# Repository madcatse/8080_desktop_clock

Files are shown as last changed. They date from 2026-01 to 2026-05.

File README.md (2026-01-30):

# i8080 homebrew digital clock/weather station (fork)

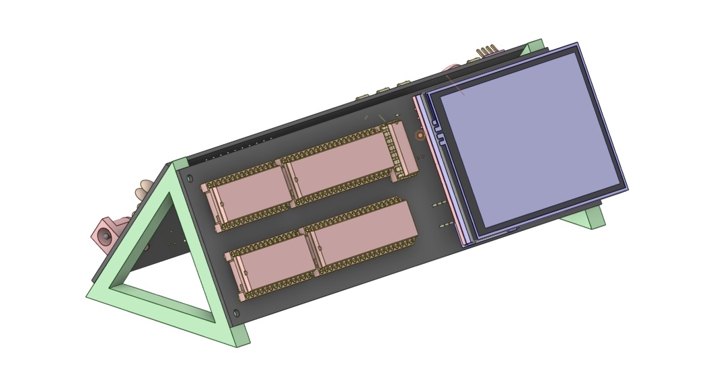
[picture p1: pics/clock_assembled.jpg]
Передняя плата

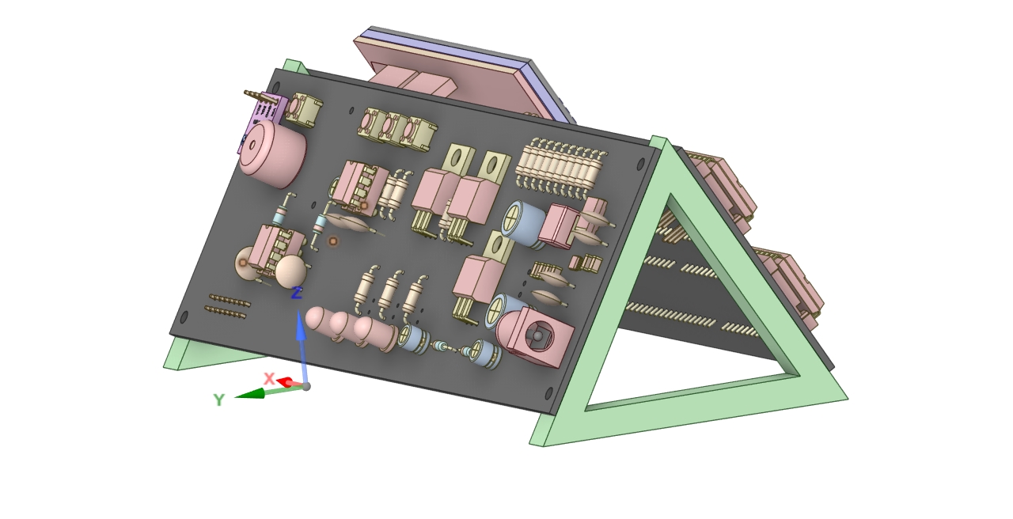
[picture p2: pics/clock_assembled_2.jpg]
Задняя плата

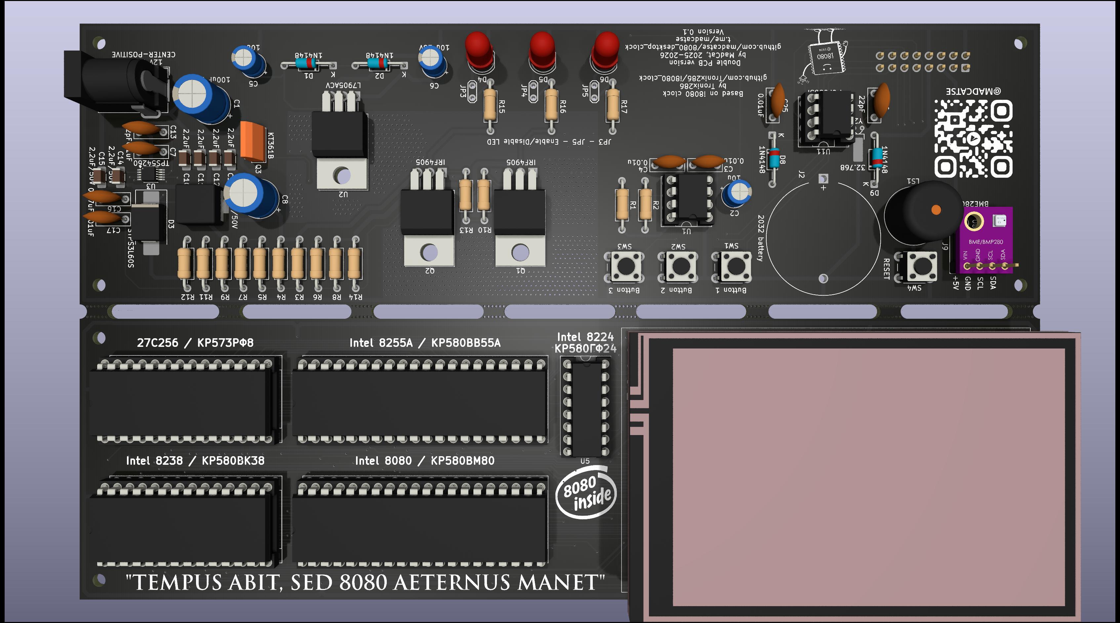
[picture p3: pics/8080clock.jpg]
Плата проекта в сборе


## Русский

Этот репозиторий — форк проекта **"i8080 homebrew digital clock/weather station"** автора **Tronix286**: 
<https://github.com/Tronix286/i8080_clock>.

Моя цель — сделать часы более презентабельными и свести к минимуму использование SMD‑компонентов (с таким процессором использовать их «не комильфо»). Я очень благодарен автору за схему и само устройство — без этой базы не получилось бы так быстро продвинуться.

Ключевое отличие от исходного проекта: в этом форке сделан упор на внешний вид и на максимально сквозной/выводной монтаж, поэтому плата и компоновка ориентированы на более «классическое» исполнение и удобство сборки, при сохранении общей архитектуры.

### Что внутри

**Аппаратная часть**
- Плата i8080‑совместимого компьютера с тактированием, шиной, ПЗУ/ОЗУ и часами реального времени.
- Внешние устройства: TFT‑дисплей, датчики по I2C и 1‑Wire, кнопки.

**Проект в KiCad**
- Полный проект схемы и платы находится в каталоге `hardware/`.

### ПО

Сборка прошивки описана в каталоге `software/` (используется z88dk и собственная цель `clock80`).

### 3D

Трехмерная модель собранных часов, а также модели треугольные ножки для 3d-печати.

---

## English

This repository is a fork of **"i8080 homebrew digital clock/weather station"** by **Tronix286**: 
<https://github.com/Tronix286/i8080_clock>.

My goal is to make the clock look more presentable and to minimize the number of SMD parts (with a CPU like this, using SMD feels out of place). I am very grateful to the author for the schematic and the original device — it provided the essential foundation for this work.

Key difference vs the original project: this fork focuses on the physical appearance and on keeping the design as through‑hole as possible. The PCB layout and mechanical decisions are tailored to a more classic, build‑friendly presentation while preserving the overall architecture.

### What’s inside

**Hardware**
- i8080‑compatible system board with clocking, bus, ROM/RAM, and real‑time clock.
- External devices: TFT display, I2C and 1‑Wire sensors, and buttons.

**KiCad project**
- Full schematic and PCB project live under `hardware/`.

### Software

Firmware build instructions and sources are in `software/` (z88dk with a custom `clock80` target).

### 3D

3D model of assembled clock, and models of triangle stands for 3d printing.

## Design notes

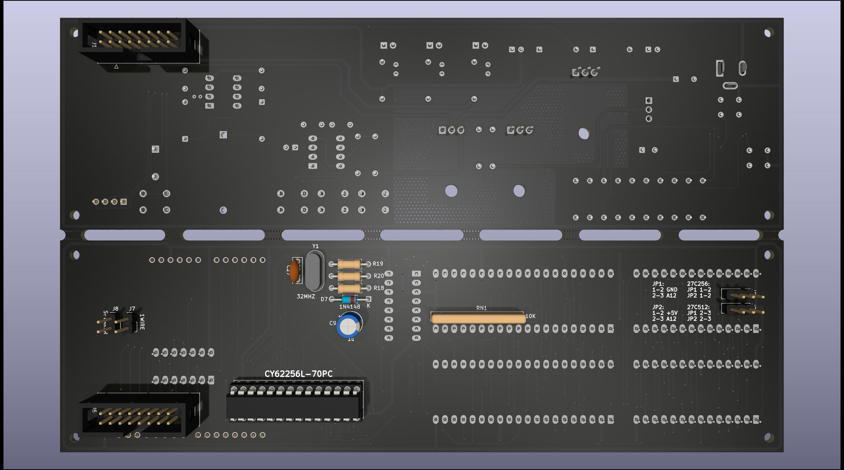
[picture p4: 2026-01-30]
pics/8080clock_backside.jpg

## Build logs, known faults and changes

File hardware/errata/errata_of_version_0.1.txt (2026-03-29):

сдвинуть резисторную сборку
диаметры вентиляционных отверстий
сделать упоминание про конденсаторы, может сделать новые отверстия
дорожка питания к часовой микросхеме
переразвернуть платы чтобы они соединялись снизу, чтобы не шлифовать верх плат
Транзистор заменить на Кт315 или BC337 и поправить цоколевку

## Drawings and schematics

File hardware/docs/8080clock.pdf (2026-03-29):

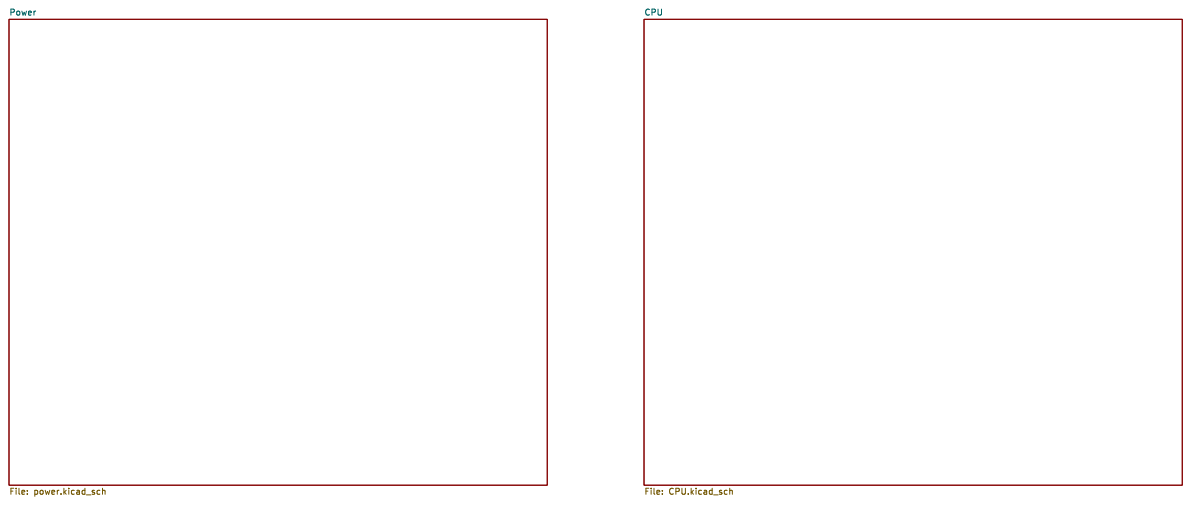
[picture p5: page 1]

Id: 1/3 Title: File: 8080clock.kicad_sch Sheet: /

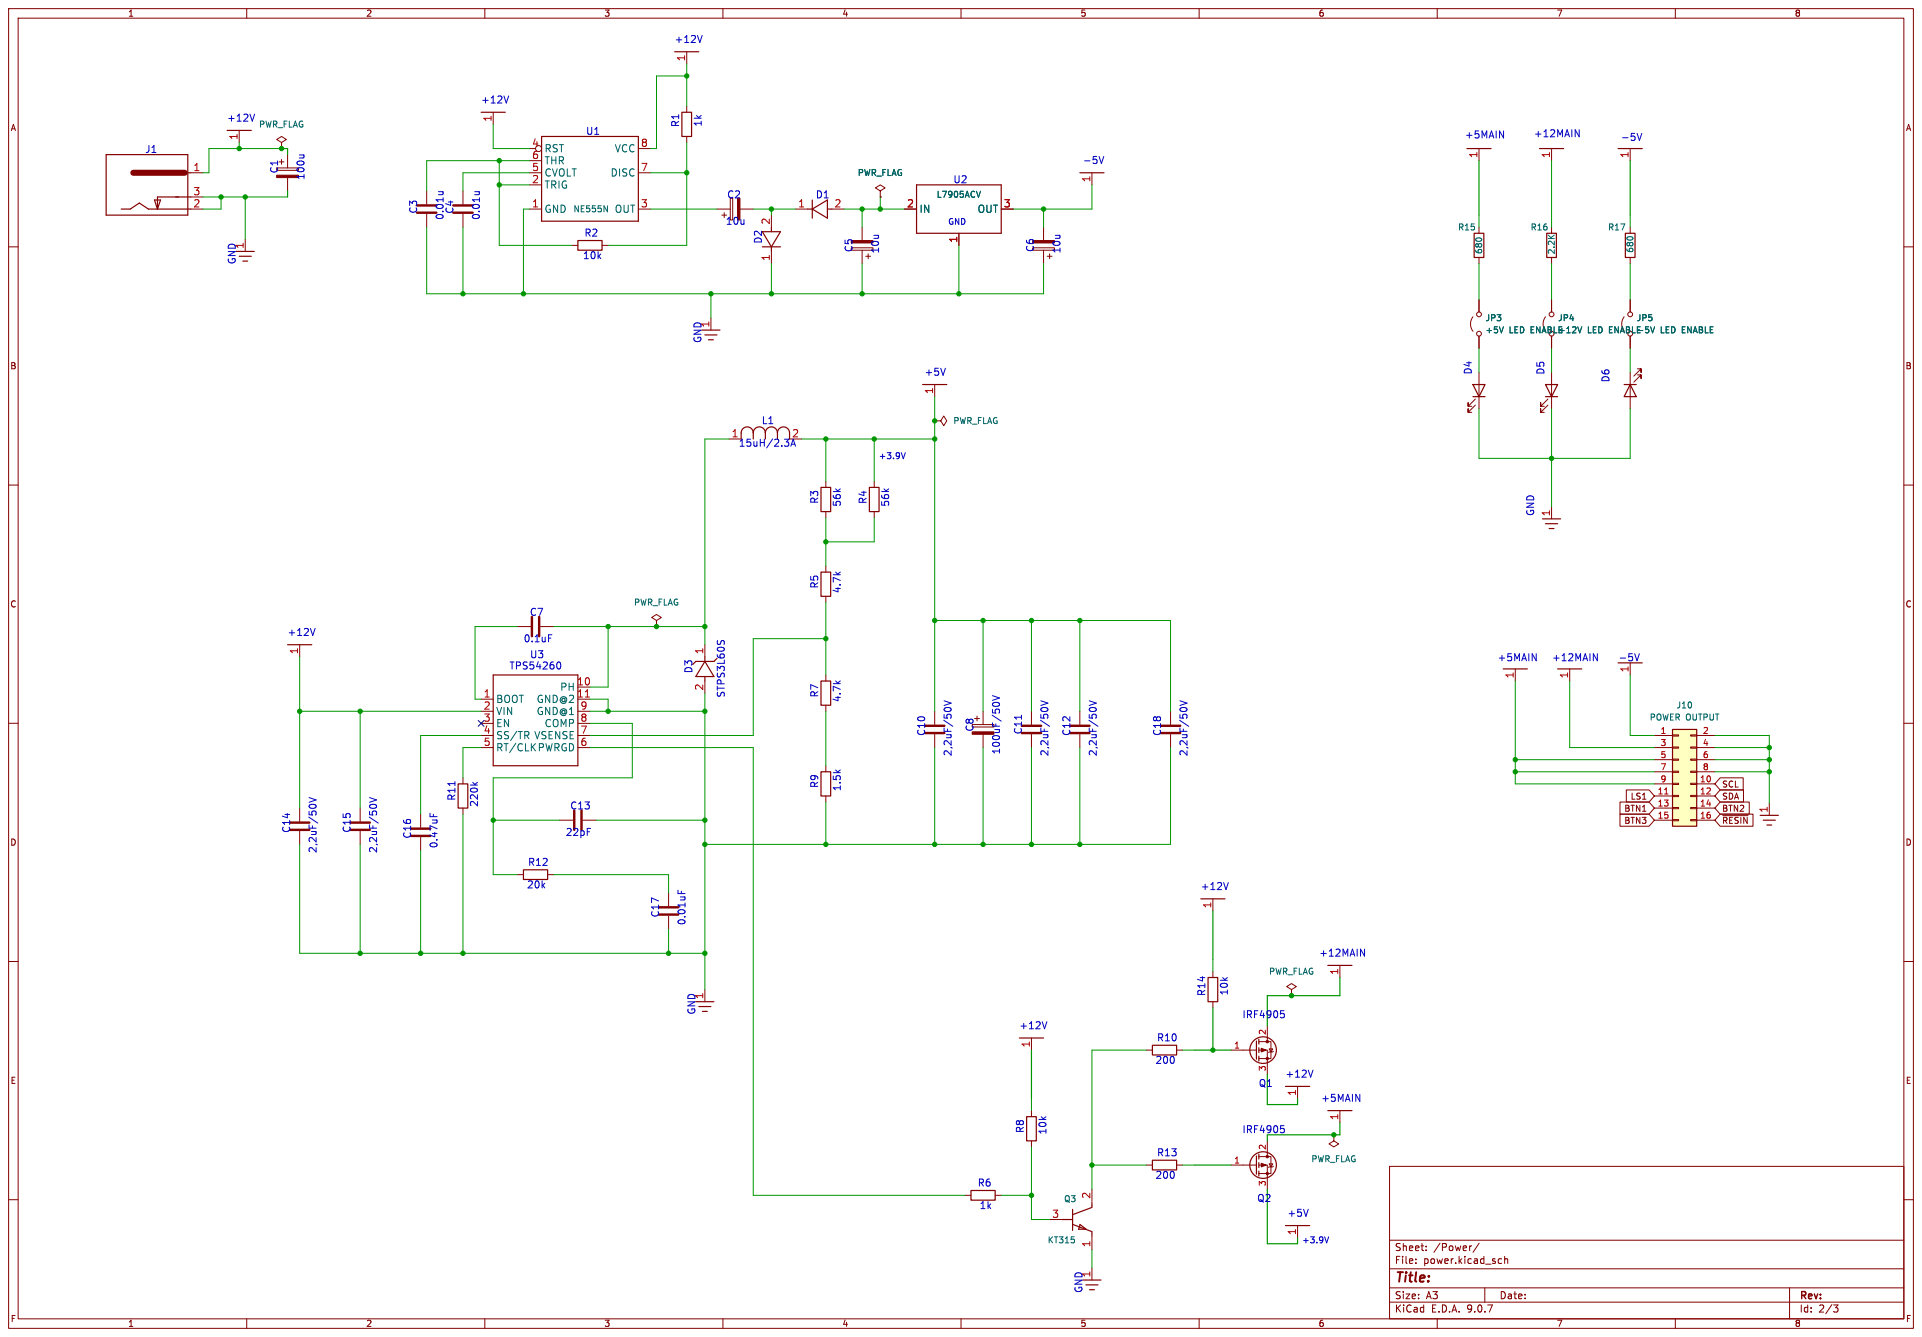
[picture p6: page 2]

1 RST 4 THR 6 CVOLT 5 TRIG 2 GND 1 VCC 8 DISC 7 OUT 3 NE555N

1 BOOT 1 VIN 2 EN 3 SS/TR 4 RT/CLK 5 PH 10 GND@2 11 GND@1 9 COMP 8 VSENSE 7 PWRGD 6

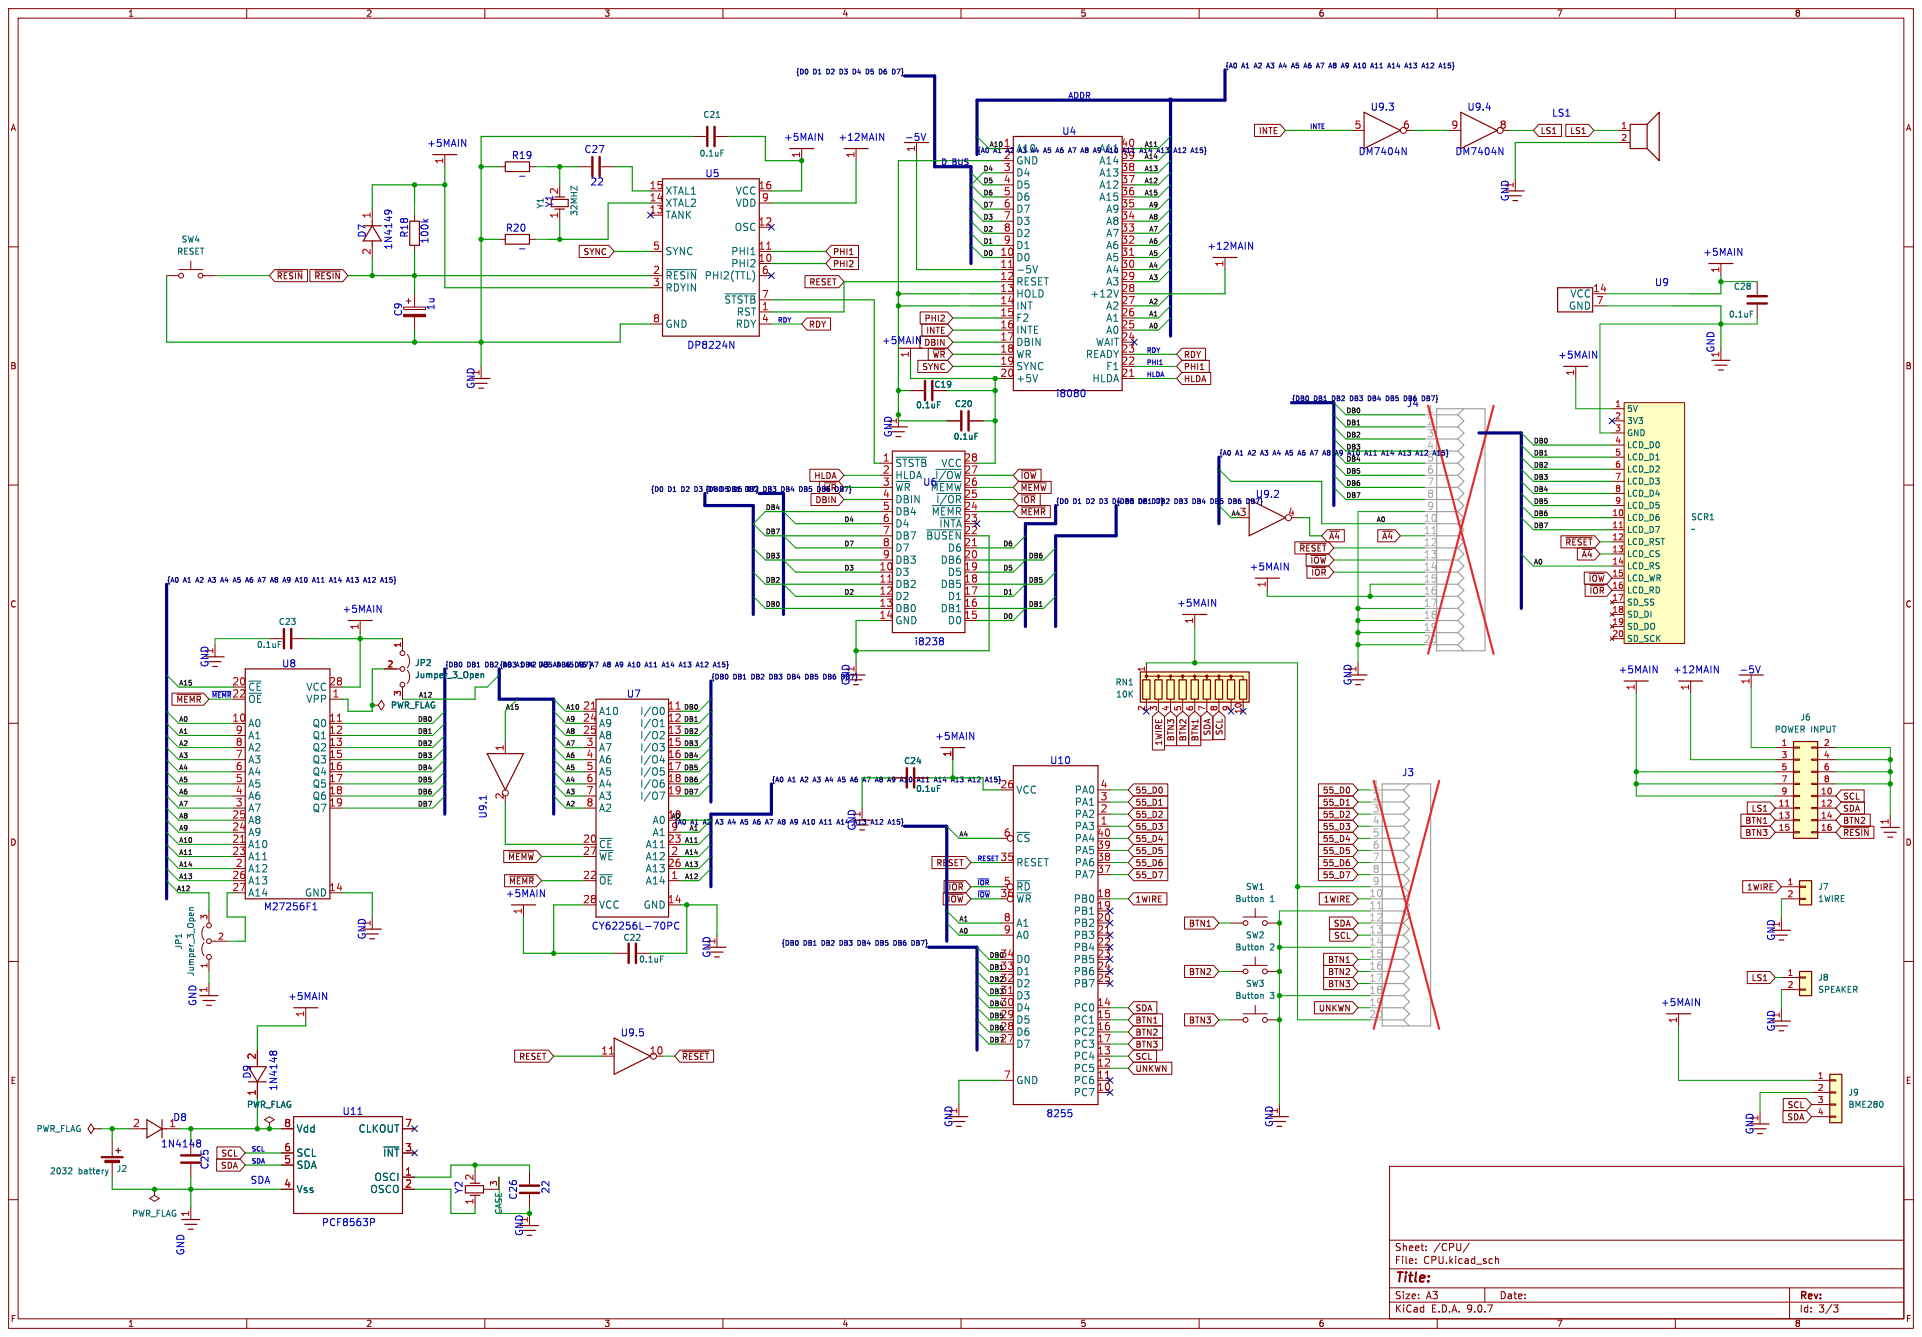
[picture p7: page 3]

1 A10 21 A9 24 A8 25 A7 3 A6 4 A5 5 A4 6 A3 7 A2 8 ~{CE} 20 ~{WE} 27 ~{OE} 22 VCC 28

1 XTAL1 15 XTAL2 14 TANK 13 SYNC 5 ~{RESIN} 2 RDYIN 3 GND 8 VCC16 VDD 9 OSC 12 PHI1 11 PHI2 10 PHI2(TTL) 6 ~{STSTB}7 RST 1 RDY 4 C20

1 ~{STSTB} 1 HLDA 2 ~{WR} 3 DBIN 4 DB4 5 D4 6 DB7 7 D7 8 DB3 9 D3 10 DB2 11 D2 12 DB0 13 GND 14 VCC28 ~{I/OW}27 ~{MEMW} 26 ~{I/OR}25 ~{MEMR} 24 ~{INTA} 23 ~{BUSEN} 22 D6 21 DB6 20 D5 19 DB5 18 D1 17 DB1 16 D0 15

1 VCC 26 ~{CS} 6 RESET 35 ~{RD} 5 ~{WR} 36 A1 8 A0 9 D0 34 D1 33 D2 32 D3 31 D4 30 D5 29 D6 28 D7 27 GND 7 PA0 4 PA1 3 PA2 2 PA3 1 PA4 40 PA5 39 PA6 38 PA7 37 PB0 18 PB1 19 PB2 20 PB3 21 PB4 22 PB5 23 PB6 24 PB7 25 PC0 14 PC1 15 PC2 16 PC3 17 PC4 13 PC5 12 PC6 11 PC7 10

Id: 3/3 Title: File: CPU.kicad_sch Sheet: /CPU/

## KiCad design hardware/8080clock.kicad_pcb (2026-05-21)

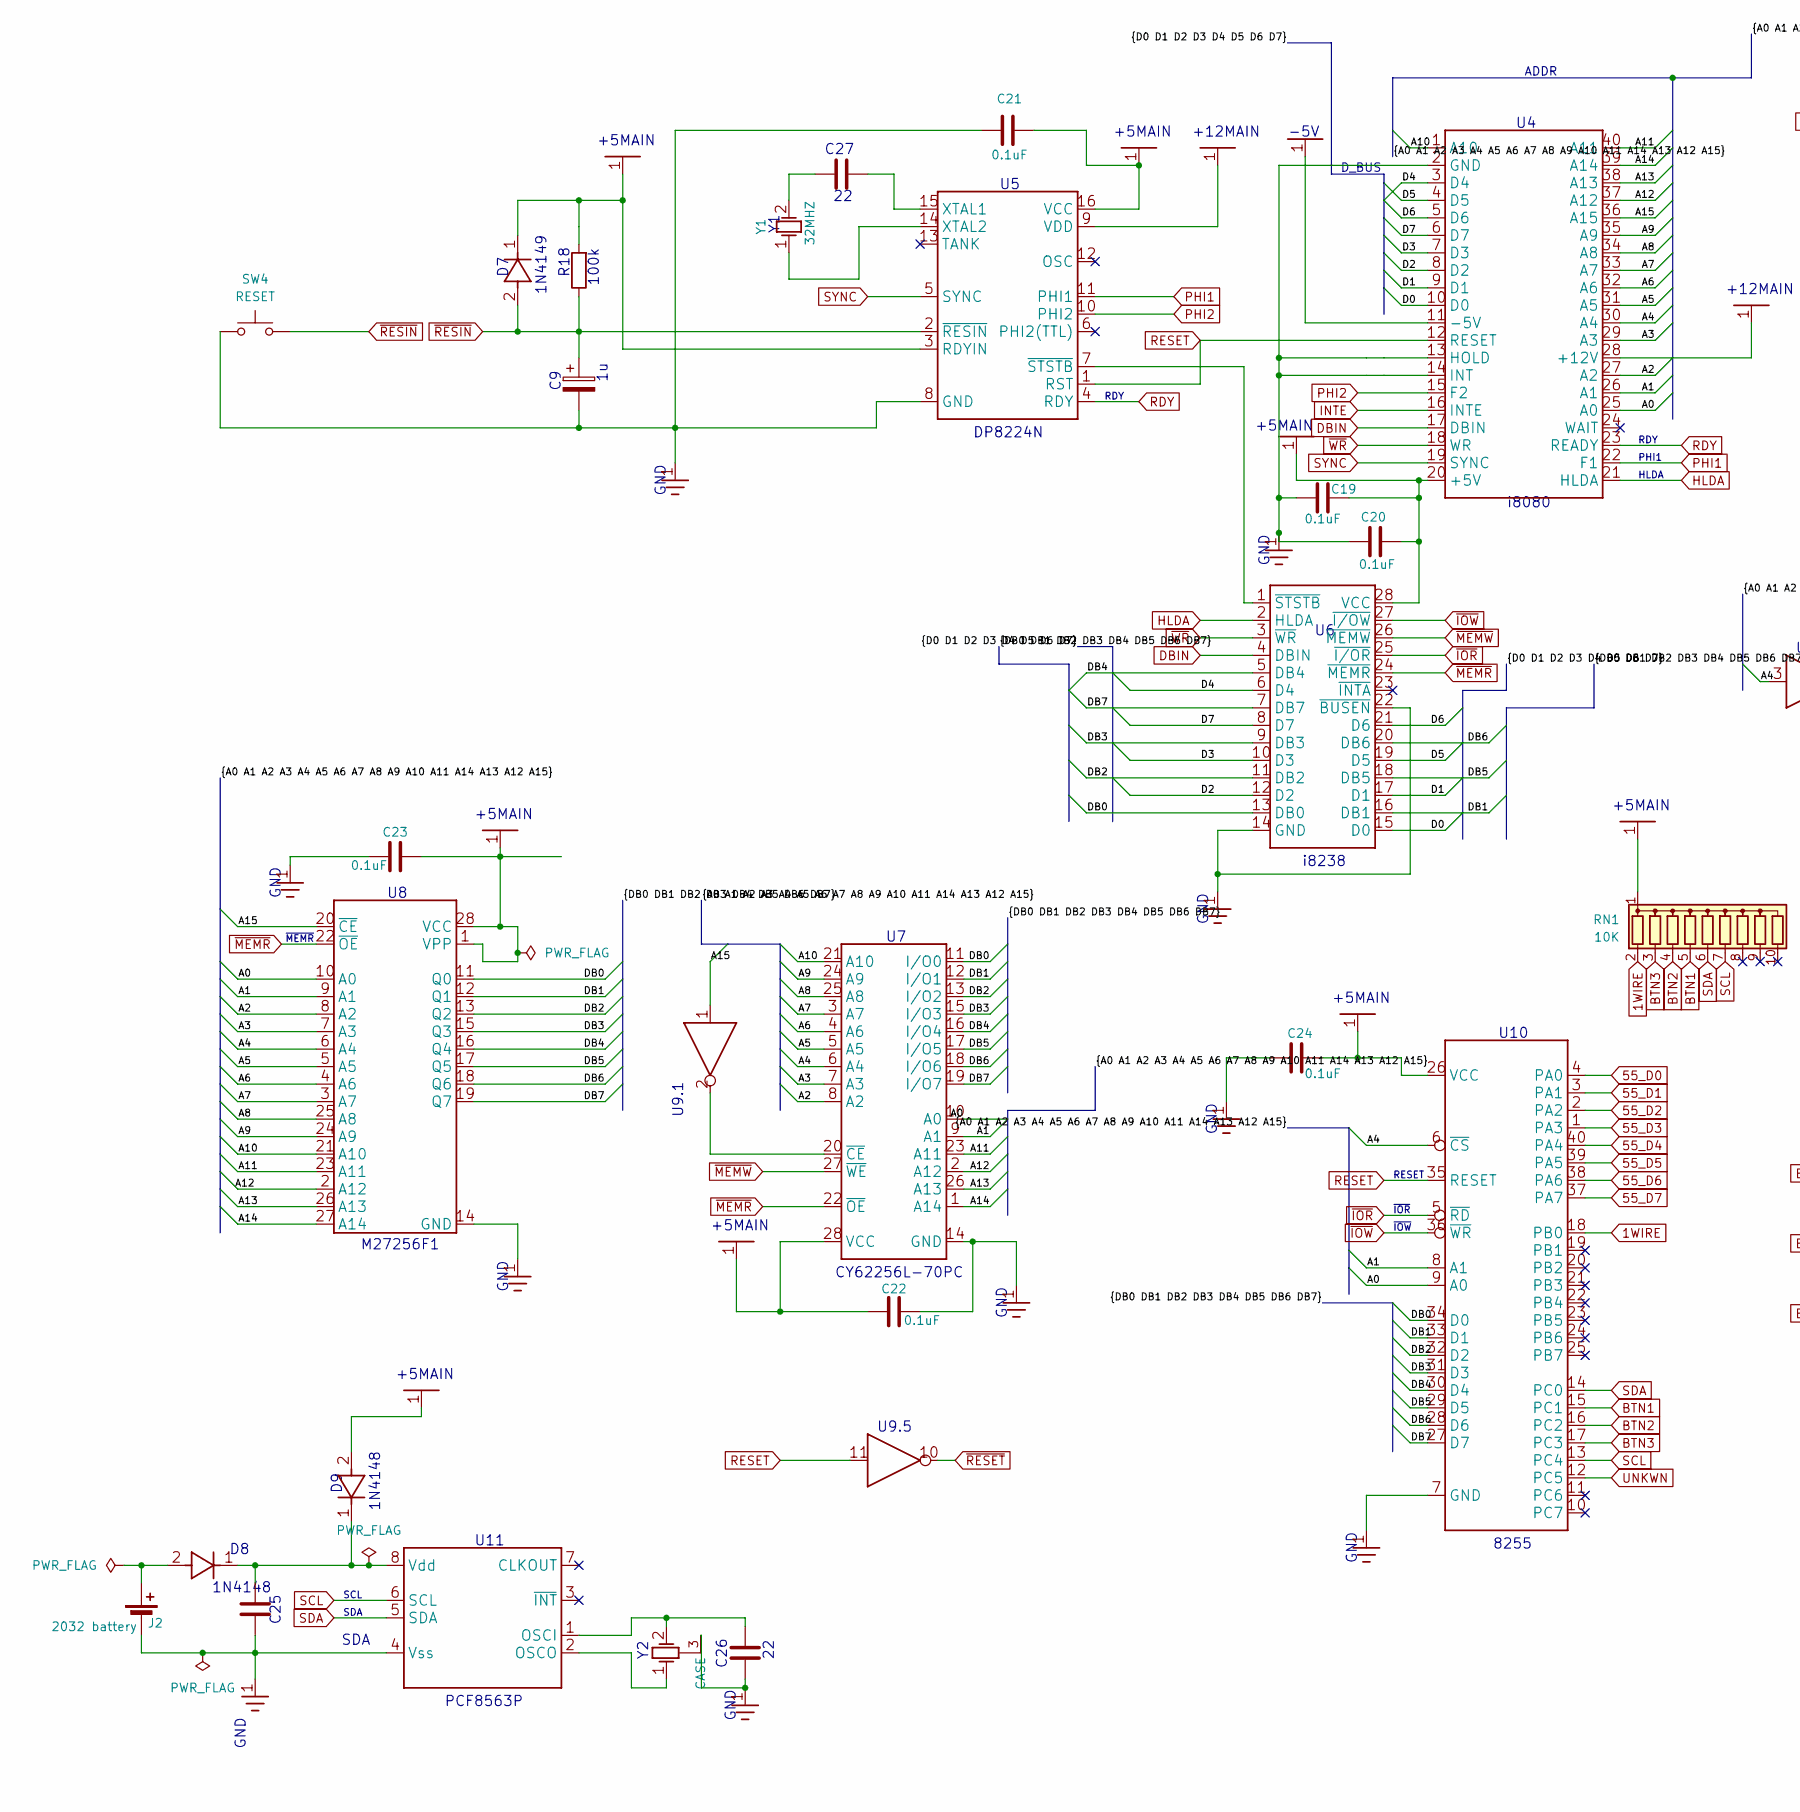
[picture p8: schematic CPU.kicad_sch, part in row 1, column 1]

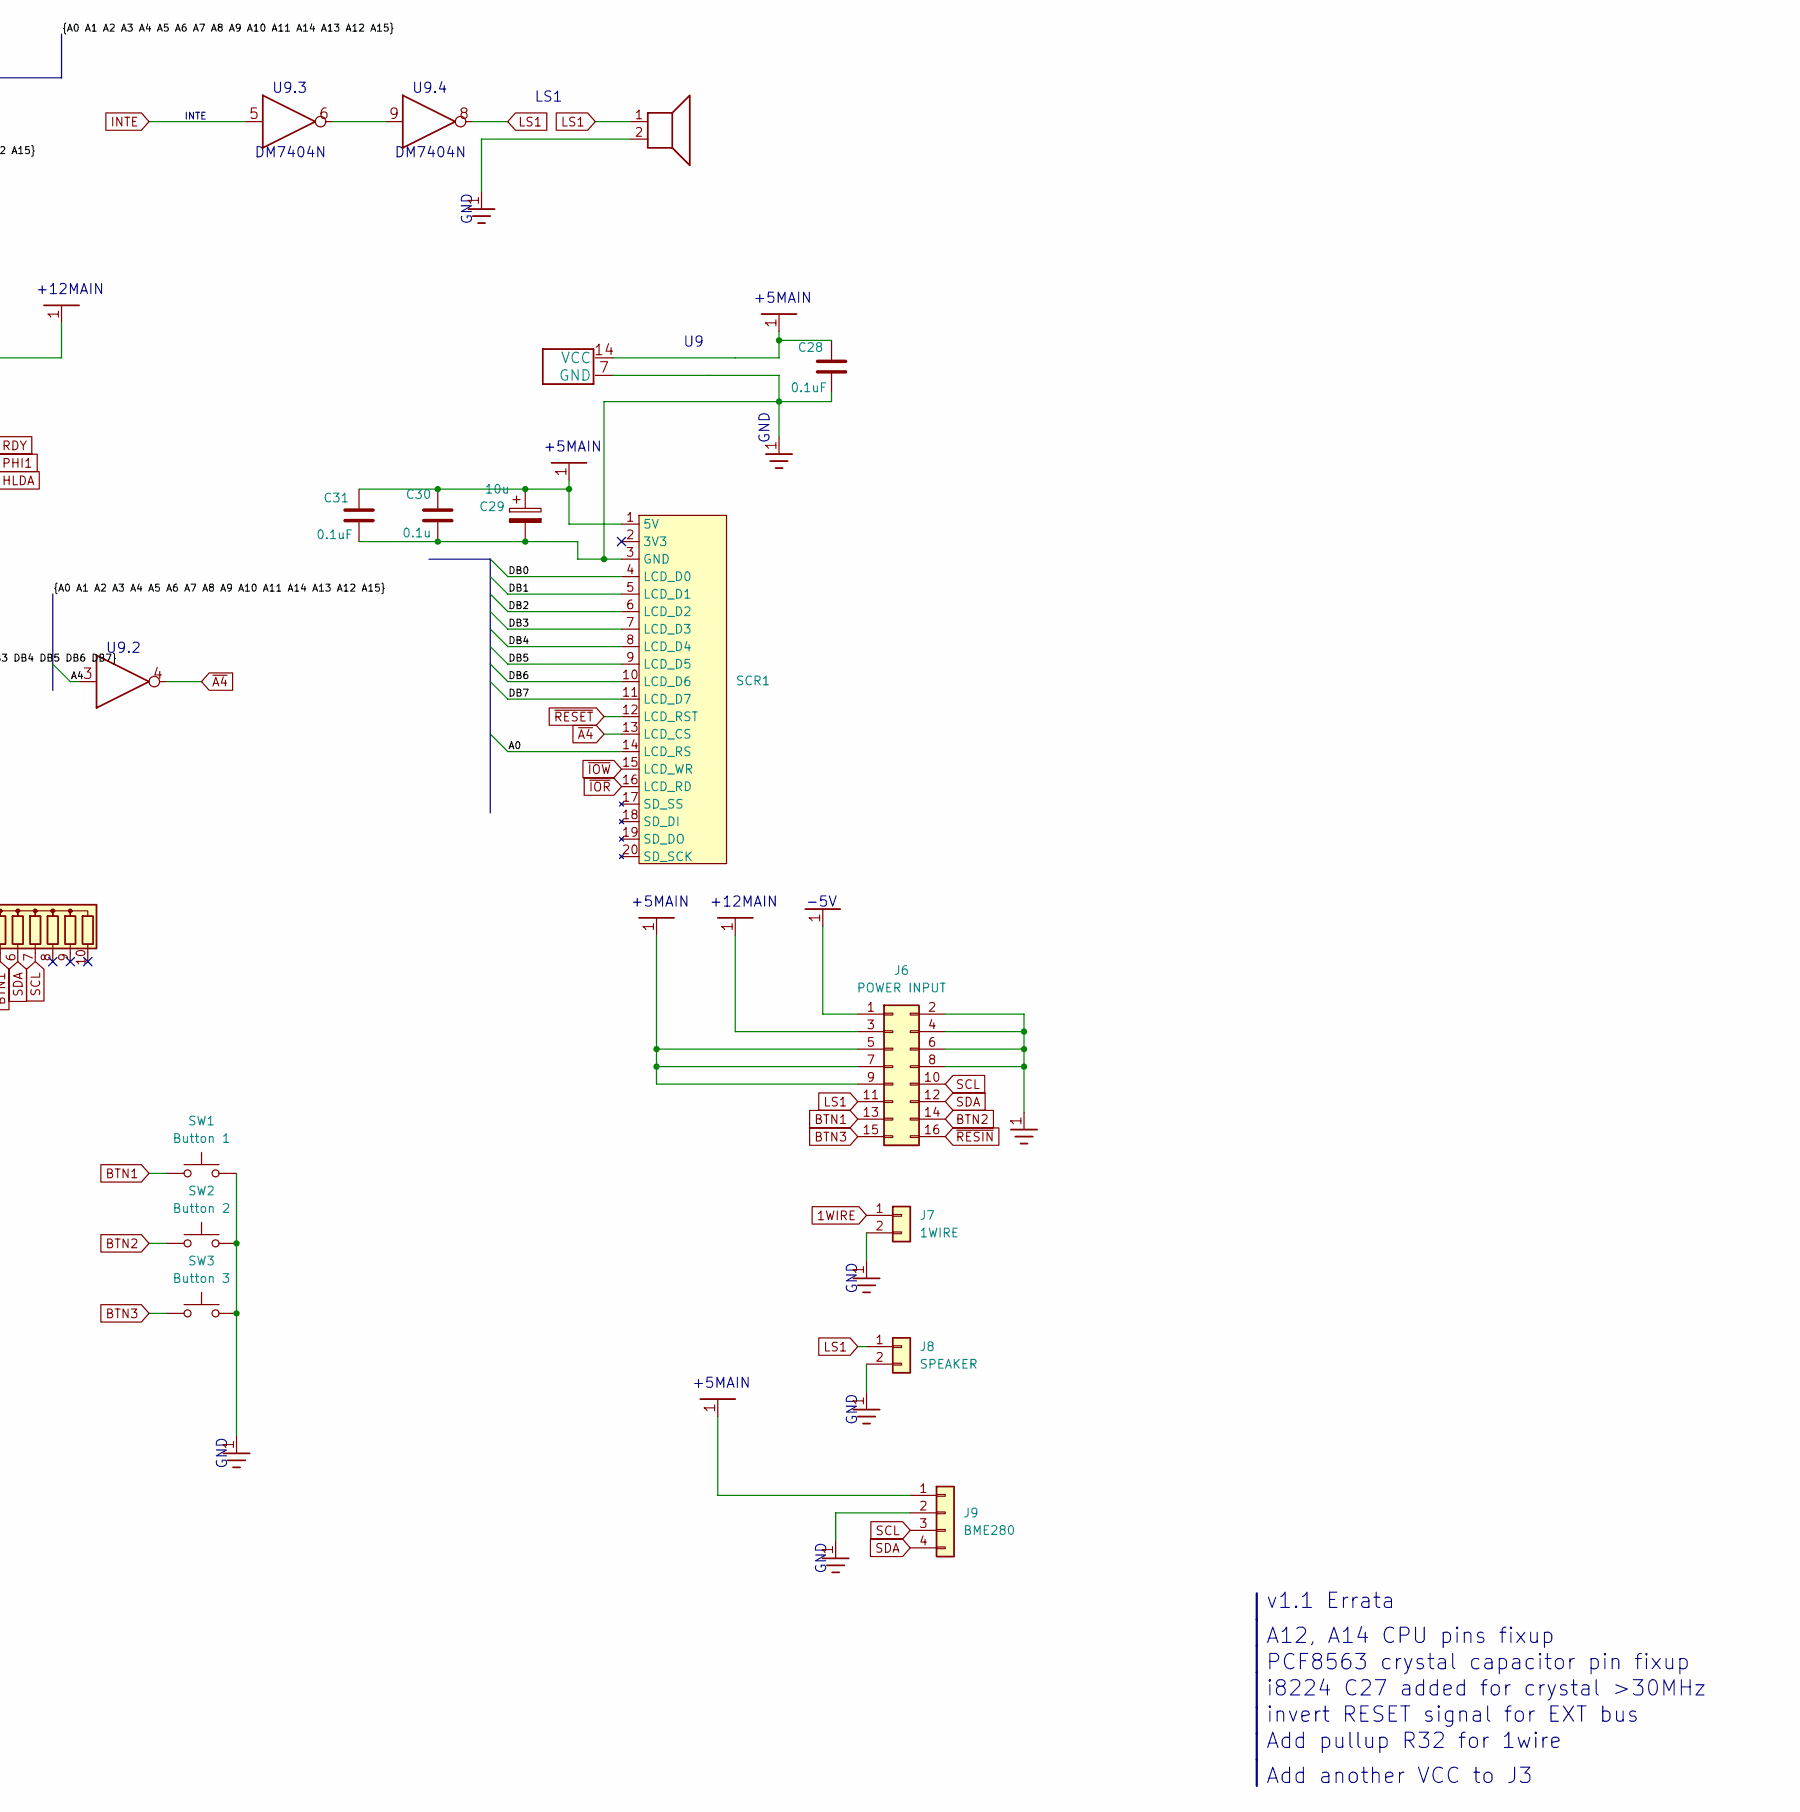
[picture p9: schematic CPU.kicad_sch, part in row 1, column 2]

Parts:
C9: 1u; CP_Radial_D6.3mm_P2.50mm
C19, C20, C21, C22, C23, C24, C28, C31: 0.1uF; C_Disc_D7.0mm_W2.5mm_P5.00mm
C25: 0.01uF; C_Disc_D7.0mm_W2.5mm_P5.00mm
C26, C27: 22pF; C_Disc_D7.0mm_W2.5mm_P5.00mm
C29: 10u; CP_Radial_D5.0mm_P2.50mm
C30: 0.1u; C_Disc_D7.0mm_W2.5mm_P5.00mm
D7, D8, D9: 1N4148; D_DO-35_SOD27_P10.16mm_Horizontal
J2: 2032 battery; BatteryHolder_MYOUNG_BS-07-A1BJ001_CR2032
J6: POWER INPUT; IDC-Header_2x08_P2.54mm_Vertical
J7: 1WIRE; PinHeader_1x02_P2.54mm_Vertical
J8: SPEAKER; PinHeader_1x02_P2.54mm_Vertical
J9: BME280; BME280_sensor
LS1: AI-1223-TWT-5V-R; Buzzer_12x9.5RM7.6
R18: 100k; R_Axial_DIN0207_L6.3mm_D2.5mm_P10.16mm_Horizontal
RN1: 10K; R_Array_SIP10
SCR1: SCREEN
SW1: Button 1; SW_PUSH_6mm
SW2: Button 2; SW_PUSH_6mm
SW3: Button 3; SW_PUSH_6mm
SW4: RESET; SW_PUSH_6mm
U5: Intel 8224 / КР580ГФ24; DIP-16_W7.62mm_Socket_LongPads
U6: Intel 8238 / КР580ВК38; DIP-28_W15.24mm_Socket_LongPads
U7: CY62256L-70PC; DIP-28_W7.62mm_Socket_LongPads
U8: 27C256 / КР573РФ8; DIP-28_W15.24mm_Socket_LongPads
U9: 74LS04 / К555ЛН1; DIP-14_W7.62mm_Socket_LongPads
U10: Intel 8255A / КР580ВВ55А; DIP-40_W15.24mm_Socket_LongPads
U11: PCF8563P; DIP-8_W7.62mm_Socket_LongPads
U12: Intel 8080 / КР580ВМ80; DIP-40_W15.24mm_Socket_LongPads
Y1: 32MHZ; Crystal_HC49-4H_Vertical
Y2: 32.768; Crystal_DS15_D1.5mm_L5.0mm_Horizontal_1EP_style1

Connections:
1WIRE: J7.1, RN1.2 (R1), U10.18 (PB0)
55_D0: U10.4 (PA0)
55_D1: U10.3 (PA1)
55_D2: U10.2 (PA2)
55_D3: U10.1 (PA3)
55_D4: U10.40 (PA4)
55_D5: U10.39 (PA5)
55_D6: U10.38 (PA6)
55_D7: U10.37 (PA7)
+5MAIN: C19.2, C20.2, C21.1, C22.1, C23.2, C24.2, C28.2, C29.1, C30.2, C31.2, D7.1 (K), D9.2 (A), J6.5, J6.7, J6.9, J9.1, R18.2, RN1.1 (common), SCR1.1 (5V), U5.3 (RDYIN), U5.16 (VCC), U6.28 (VCC), U7.28 (VCC), U8.1 (VPP), U8.28 (VCC), U9.14 (VCC), U10.26 (VCC), U12.20 (+5V); also elsewhere on the board
+12MAIN: J6.3, U5.9 (VDD), U12.28 (+12V); also elsewhere on the board
-5V: J6.1, U12.11 (-5V); also elsewhere on the board
/CPU/A0: SCR1.14 (LCD_RS), U7.10 (A0), U8.10 (A0), U10.9 (A0), U12.25 (A0)
/CPU/A1: U7.9 (A1), U8.9 (A1), U10.8 (A1), U12.26 (A1)
/CPU/A2: U7.8 (A2), U8.8 (A2), U12.27 (A2)
/CPU/A3: U7.7 (A3), U8.7 (A3), U12.29 (A3)
/CPU/A4: U7.6 (A4), U8.6 (A4), U9.3 (A), U10.6 (~CS), U12.30 (A4)
/CPU/A5: U7.5 (A5), U8.5 (A5), U12.31 (A5)
/CPU/A6: U7.4 (A6), U8.4 (A6), U12.32 (A6)
/CPU/A7: U7.3 (A7), U8.3 (A7), U12.33 (A7)
/CPU/A8: U7.25 (A8), U8.25 (A8), U12.34 (A8)
/CPU/A9: U7.24 (A9), U8.24 (A9), U12.35 (A9)
/CPU/A10: U7.21 (A10), U8.21 (A10), U12.1 (A10)
/CPU/A11: U7.23 (A11), U8.23 (A11), U12.40 (A11)
/CPU/A12: U7.2 (A12), U8.2 (A12), U12.37 (A12)
/CPU/A13: U7.26 (A13), U8.26 (A13), U12.38 (A13)
/CPU/A14: U7.1 (A14), U8.27 (A14), U12.39 (A14)
/CPU/A15: U8.20 (~CE), U9.1 (A), U12.36 (A15)
/CPU/D0: U6.15 (D0), U12.10 (D0)
/CPU/D1: U6.17 (D1), U12.9 (D1)
/CPU/D2: U6.12 (D2), U12.8 (D2)
/CPU/D3: U6.10 (D3), U12.7 (D3)
/CPU/D4: U6.6 (D4), U12.3 (D4)
/CPU/D5: U6.19 (D5), U12.4 (D5)
/CPU/D6: U6.21 (D6), U12.5 (D6)
/CPU/D7: U6.8 (D7), U12.6 (D7)
/CPU/DB0: SCR1.4 (LCD_D0), U6.13 (DB0), U7.11 (I/O0), U8.11 (Q0), U10.34 (D0)
/CPU/DB1: SCR1.5 (LCD_D1), U6.16 (DB1), U7.12 (I/O1), U8.12 (Q1), U10.33 (D1)
/CPU/DB2: SCR1.6 (LCD_D2), U6.11 (DB2), U7.13 (I/O2), U8.13 (Q2), U10.32 (D2)
/CPU/DB3: SCR1.7 (LCD_D3), U6.9 (DB3), U7.15 (I/O3), U8.15 (Q3), U10.31 (D3)
/CPU/DB4: SCR1.8 (LCD_D4), U6.5 (DB4), U7.16 (I/O4), U8.16 (Q4), U10.30 (D4)
/CPU/DB5: SCR1.9 (LCD_D5), U6.18 (DB5), U7.17 (I/O5), U8.17 (Q5), U10.29 (D5)
/CPU/DB6: SCR1.10 (LCD_D6), U6.20 (DB6), U7.18 (I/O6), U8.18 (Q6), U10.28 (D6)
/CPU/DB7: SCR1.11 (LCD_D7), U6.7 (DB7), U7.19 (I/O7), U8.19 (Q7), U10.27 (D7)
BTN1: J6.13, RN1.5 (R4), SW1.2, U10.15 (PC1); also elsewhere on the board
BTN2: J6.14, RN1.4 (R3), SW2.2, U10.16 (PC2); also elsewhere on the board
BTN3: J6.15, RN1.3 (R2), SW3.2, U10.17 (PC3); also elsewhere on the board
DBIN: U6.4 (DBIN), U12.17 (DBIN)
GND: C9.2, C19.1, C20.1, C21.2, C22.2, C23.1, C24.1, C25.1, C26.2, C28.1, C29.2, C30.1, C31.1, J2.2 (-), J6.2, J6.4, J6.6, J6.8, J7.2, J8.2, J9.2, LS1.2, SCR1.3 (GND), SW1.1, SW2.1, SW3.1, SW4.2, U5.8 (GND), U6.14 (GND), U6.22 (~BUSEN), U7.14 (GND), U8.14 (GND), U9.7 (GND), U10.7 (GND), U11.4 (Vss), U12.2 (GND), U12.13 (HOLD), U12.14 (INT), Y2.3 (CASE); also elsewhere on the board
HLDA: U6.2 (HLDA), U12.21 (HLDA)
INTE: U9.5 (A), U12.16 (INTE)
LS1: J6.11, J8.1, LS1.1, U9.8 (Y); also elsewhere on the board
unnamed: D8.2 (A), J2.1 (+)
unnamed: C25.2, D8.1 (K), D9.1 (K), U11.8 (Vdd)
unnamed: C27.2, U5.15 (XTAL1)
unnamed: U5.14 (XTAL2), Y1.1 (OSC1)
unnamed: U5.7 (~STSTB), U6.1 (~STSTB)
unnamed: U7.20 (~CE), U9.2 (Y)
unnamed: U9.6 (Y), U9.9 (A)
unnamed: C26.1, U11.1 (OSCI), Y2.2 (OSC2)
unnamed: U11.2 (OSCO), Y2.1 (OSC1)
unnamed: C27.1, Y1.2 (OSC2)
PHI1: U5.11 (PHI1), U12.22 (F1)
PHI2: U5.10 (PHI2), U12.15 (F2)
RDY: U5.4 (RDY), U12.23 (READY)
RESET: U5.1 (RST), U9.11 (A), U10.35 (RESET), U12.12 (RESET)
SCL: J6.10, J9.3, RN1.7 (R6), U10.13 (PC4), U11.6 (SCL); also elsewhere on the board
SDA: J6.12, J9.4, RN1.6 (R5), U10.14 (PC0), U11.5 (SDA); also elsewhere on the board
SYNC: U5.5 (SYNC), U12.19 (SYNC)
UNKWN: U10.12 (PC5)
~A4: SCR1.13 (LCD_CS), U9.4 (Y)
~IOR: SCR1.16 (LCD_RD), U6.25 (~I/OR), U10.5 (~RD)
~IOW: SCR1.15 (LCD_WR), U6.27 (~I/OW), U10.36 (~WR)
~MEMR: U6.24 (~MEMR), U7.22 (~OE), U8.22 (~OE)
~MEMW: U6.26 (~MEMW), U7.27 (~WE)
~RESET: SCR1.12 (LCD_RST), U9.10 (Y)
~RESIN: C9.1, D7.2 (A), J6.16, R18.1, SW4.1, U5.2 (~RESIN); also elsewhere on the board
~WR: U6.3 (~WR), U12.18 (WR)

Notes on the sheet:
GND
-5V
U9.2
LS1
U9.3
1N4148
R18
+5MAIN
PCF8563 crystal capacitor pin fixup
SDA
A12, A14 CPU pins fixup
D_BUS
U9.1
~{IOR}
+12MAIN
Add another VCC to J3
RDY
~{IOW}
U9.4
100k
DM7404N
C27
U10
C25
C26
CY62256L-70PC
PHI1
v1.1 Errata
~{MEMR}
U9.5
invert RESET signal for EXT bus
PCF8563P
INTE
RESET
i8080
SCL
HLDA
Add pullup R32 for 1wire
i8224 C27 added for crystal >30MHz
M27256F1

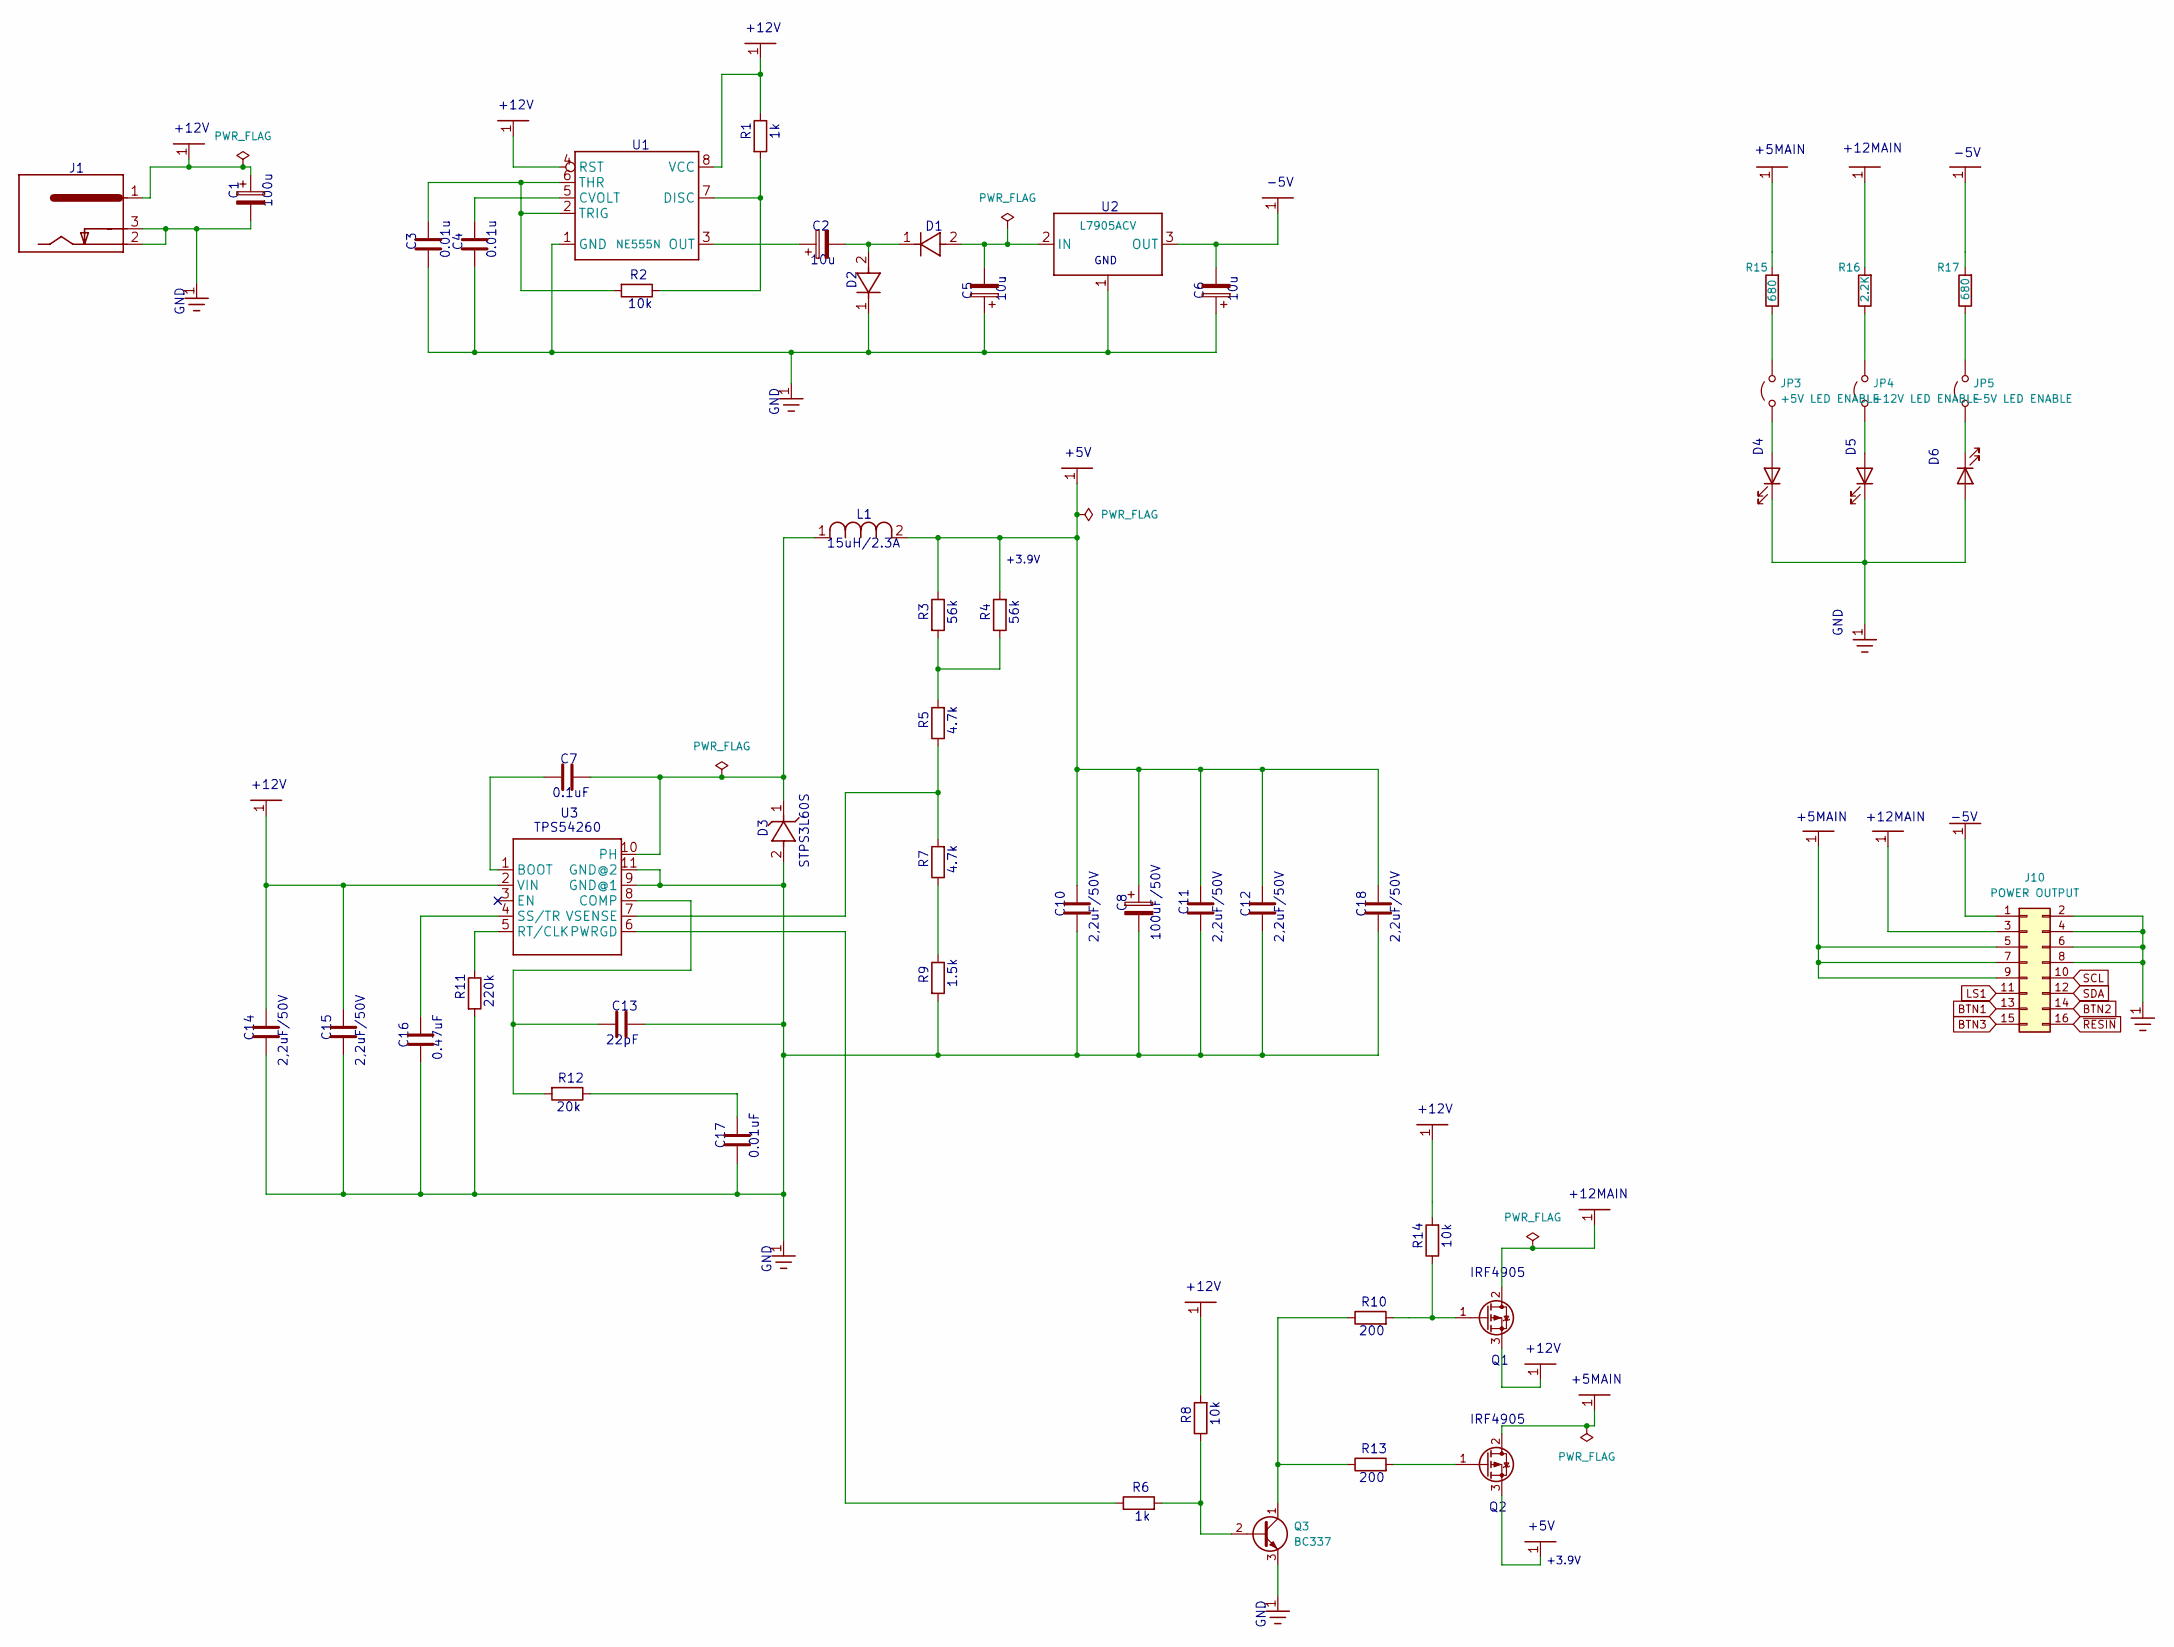
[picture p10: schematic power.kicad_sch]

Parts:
C1: 100uF 25V; CP_Radial_D8.0mm_P5.00mm
C2, C5: 10u; CP_Radial_D5.0mm_P2.50mm
C3, C4: 0.01u; C_Disc_D7.0mm_W2.5mm_P5.00mm
C6: 10u 16V; CP_Radial_D5.0mm_P2.50mm
C7: 0.1uF; C_Disc_D7.0mm_W2.5mm_P5.00mm
C8: 100uF/50V; CP_Radial_D8.0mm_P3.50mm
C10, C11, C12, C18: 2,2uF; C_1206_3216Metric_Pad1.33x1.80mm_HandSolder
C13: 22pF; C_Disc_D7.0mm_W2.5mm_P5.00mm
C14, C15: 2,2uF/50V; C_1206_3216Metric_Pad1.33x1.80mm_HandSolder
C16: 0.47uF; C_Disc_D7.0mm_W2.5mm_P5.00mm
C17: 0.01uF; C_Disc_D7.0mm_W2.5mm_P5.00mm
D1, D2: 1N4148; D_DO-35_SOD27_P10.16mm_Horizontal
D3: STPS3L60S; D_SMC_Handsoldering
D4: +5V; LED_D5.0mm
D5: +12V; LED_D5.0mm
D6: -5V; LED_D5.0mm
J1: 4840-2201; BarrelJack_GCT_DCJ200-10-A_Horizontal
J10: POWER OUTPUT; IDC-Header_2x08_P2.54mm_Vertical
JP3: +5V LED ENABLE; TestPoint_2Pads_Pitch2.54mm_Drill0.8mm
JP4: +12V LED ENABLE; TestPoint_2Pads_Pitch2.54mm_Drill0.8mm
JP5: -5V LED ENABLE; TestPoint_2Pads_Pitch2.54mm_Drill0.8mm
L1: 15uH/2.3A; CDRH8D43NP-100NC
Q1, Q2: IRF4905; TO-220-3_Horizontal_TabDown
Q3: BC337; TO-92L_Inline
R1, R6: 1k; R_Axial_DIN0207_L6.3mm_D2.5mm_P10.16mm_Horizontal
R2, R8, R14: 10k; R_Axial_DIN0207_L6.3mm_D2.5mm_P10.16mm_Horizontal
R3, R4: 56k; R_Axial_DIN0207_L6.3mm_D2.5mm_P10.16mm_Horizontal
R5, R7: 4.7k; R_Axial_DIN0207_L6.3mm_D2.5mm_P10.16mm_Horizontal
R9: 1.5k; R_Axial_DIN0207_L6.3mm_D2.5mm_P10.16mm_Horizontal
R10, R13: 200; R_Axial_DIN0207_L6.3mm_D2.5mm_P10.16mm_Horizontal
R11: 220k; R_Axial_DIN0207_L6.3mm_D2.5mm_P10.16mm_Horizontal
R12: 20k; R_Axial_DIN0207_L6.3mm_D2.5mm_P10.16mm_Horizontal
R15, R17: 680; R_Axial_DIN0207_L6.3mm_D2.5mm_P10.16mm_Horizontal
R16: 2.2K; R_Axial_DIN0207_L6.3mm_D2.5mm_P10.16mm_Horizontal
U1: NE555N; DIP-8_W7.62mm_Socket_LongPads
U2: L7905ACV; TO-220-3_Horizontal_TabDown
U3: TPS54260; HVSSOP-10-1EP_3x3mm_P0.5mm_EP1.57x1.88mm

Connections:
+5MAIN: J10.5, J10.7, J10.9, Q2.2 (D), R15.2; also elsewhere on the board
+5V: C8.1, C10.1, C11.1, C12.1, C18.1, L1.2, Q2.3 (S), R3.1, R4.2
+12MAIN: J10.3, Q1.2 (D), R16.2; also elsewhere on the board
+12V: C1.1, C14.1, C15.1, J1.1, Q1.3 (S), R1.1, R8.2, R14.2, U1.4 (RST), U1.8 (VCC), U3.2 (VIN)
-5V: C6.2, J10.1, R17.2, U2.3 (OUT); also elsewhere on the board
BTN1: J10.13; also elsewhere on the board
BTN2: J10.14; also elsewhere on the board
BTN3: J10.15; also elsewhere on the board
GND: C1.2, C3.1, C4.1, C5.1, C6.1, C8.2, C10.2, C11.2, C12.2, C13.2, C14.2, C15.2, C16.2, C17.2, C18.2, D2.1 (K), D3.2 (A), D4.1 (K), D5.1 (K), D6.2 (A), J1.2, J1.3, J10.2, J10.4, J10.6, J10.8, Q3.3 (E), R9.2, R11.2, U1.1 (GND), U2.1 (GND), U3.9 (GND@1), U3.11 (GND@2); also elsewhere on the board
LS1: J10.11; also elsewhere on the board
unnamed: C17.1, R12.1
unnamed: C5.2, D1.2 (A), U2.2 (IN)
unnamed: C2.2, D1.1 (K), D2.2 (A)
unnamed: C7.2, D3.1 (K), L1.1, U3.10 (PH)
unnamed: D4.2 (A), JP3.1 (A)
unnamed: D5.2 (A), JP4.1 (A)
unnamed: D6.1 (K), JP5.1 (A)
unnamed: JP3.2 (B), R15.1
unnamed: JP4.2 (B), R16.1
unnamed: JP5.2 (B), R17.1
unnamed: Q1.1 (G), R10.2, R14.1
unnamed: Q2.1 (G), R13.2
unnamed: Q3.2 (B), R6.2, R8.1
unnamed: Q3.1 (C), R10.1, R13.1
unnamed: R3.2, R4.1, R5.2
unnamed: R7.1, R9.1
unnamed: C4.2, U1.5 (CVOLT)
unnamed: R1.2, R2.1, U1.7 (DISC)
unnamed: C2.1, U1.3 (OUT)
unnamed: C3.2, R2.2, U1.2 (TRIG), U1.6 (THR)
unnamed: C7.1, U3.1 (BOOT)
unnamed: C13.1, R12.2, U3.8 (COMP)
unnamed: R6.1, U3.6 (PWRGD)
unnamed: R11.1, U3.5 (RT/CLK)
unnamed: C16.1, U3.4 (SS/TR)
unnamed: R5.1, R7.2, U3.7 (VSENSE)
SCL: J10.10; also elsewhere on the board
SDA: J10.12; also elsewhere on the board
~RESIN: J10.16; also elsewhere on the board

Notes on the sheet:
+12MAIN
4.7k
GND
+5V
220k
10k
10u
C13
+12V
2,2uF/50V
+3.9V
TPS54260
-5V
R11
0.47uF
IRF4905
C17
C12
C11
100uF/50V
0.1uF
200
C16
22pF
R13
R14
56k
+5MAIN
R12
C18
C14
100u
C15
C10
20k
R10
15uH/2.3A
0.01u
0.01uF
STPS3L60S

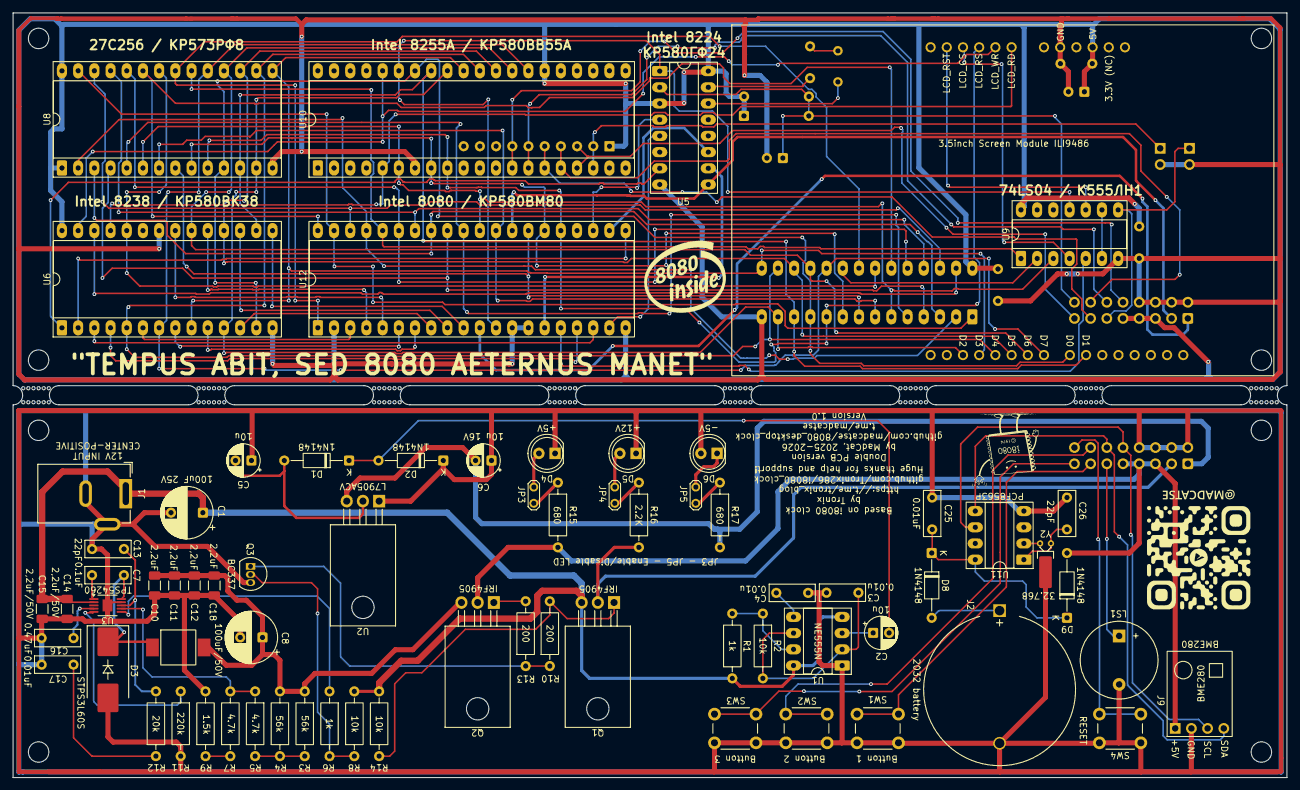
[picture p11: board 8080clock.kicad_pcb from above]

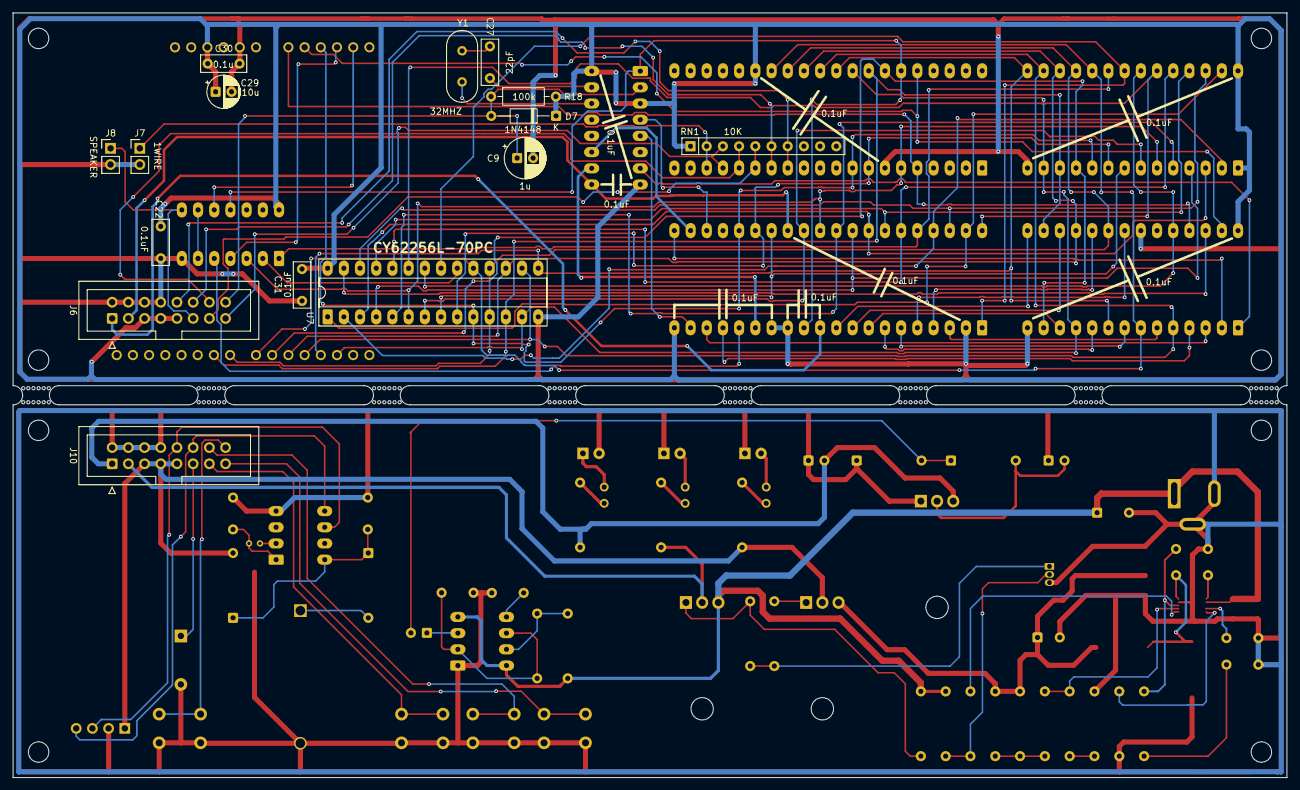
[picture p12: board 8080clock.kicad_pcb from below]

Board: 2 copper layers, 199.7 x 119.9 mm, 102 parts (15 on the bottom side), 97 nets.

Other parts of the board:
M1, M2, M3, M4, M5, M6, M7, M8: MountingHole_3.2mm_M3.0
mouse-bite-2.54mm-slot_1, mouse-bite-2.54mm-slot_2, mouse-bite-2.54mm-slot_3, mouse-bite-2.54mm-slot_4, mouse-bite-2.54mm-slot_5, mouse-bite-2.54mm-slot_6, mouse-bite-2.54mm-slot_7, mouse-bite-2.54mm-slot_13: VAL**; mouse_bite

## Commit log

2026-01-30 Initial Upload
    [8080clock.kicad_pcb, 8080clock.kicad_sch, CPU.kicad_sch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]
2026-02-17 Small fixes for holes
    [8080clock.kicad_pcb]
2026-04-02 Clock Update
    [8080clock-B_Cu.gbr, 8080clock-B_Mask.gbr, 8080clock-B_Paste.gbr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]
